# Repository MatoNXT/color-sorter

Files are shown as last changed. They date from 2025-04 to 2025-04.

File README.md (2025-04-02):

# Třídička barev pomocí Lego Mindstorms

**Autor:** Martin Mušec, třída A4b, SPSE Jecna

## 🛠️ Použitý hardware
- **EV3 Brick:** Centrální řídicí jednotka, která zpracovává informace ze senzorů a ovládá celý třídicí systém.
- **Lego Color Sensor:** Senzor, který automaticky rozpoznává barvy tříděných předmětů a umožňuje jejich rychlé roztřídění.
- **Lego Motor:** Zajišťuje pohyb pásu a přesouvání předmětů do správných pozic dle určené barvy.
- **Lego Touch Sensor:** Dotykový senzor umožňující snadné manuální spuštění a zastavení procesu třídění.
- **NXT Servo (Mindstorms) + Micro Servo SG90:** Originální servomotor řady Mindstorms NXT a malý přesný servomotor SG90, umožňující jemné a přesné třídění předmětů podle jejich barvy.

## 💻 Použitý software
- **Ev3dev + MicroPython + Pybricks:** Alternativní operační systém a programovací platforma pro LEGO EV3, umožňující snadné a efektivní programování v jazyce MicroPython.
- **VSCode + Lego Mindstorms plugin:** Vývojové prostředí pro psaní, ladění a správu kódu v Pythonu.
- **OpenSCAD:** Software pro parametrické 3D modelování speciálních součástek projektu.
- **Prusa Slicer:** Program pro přípravu modelů na 3D tisk, umožňující rychlou a přesnou výrobu dílů.
- **GitHub:** Platforma pro správu projektu, verzování a sdílení zdrojového kódu.

## 🖨️ 3D tisk a konstrukce
- **Tiskárna Prusa Mini:** Stolní 3D tiskárna vhodná pro rychlé prototypování a přesnou výrobu plastových dílů.
- **PLA filament:** Ekologicky šetrný materiál s dobrou pevností.
- **MachineBlocks:** Konstrukční prvky kompatibilní s Legem.

## 🌟 Unikátnost mého řešení
- **Programování v Pythonu:** Projekt využívá pokročilý programovací jazyk Python, což umožňuje snadnější, flexibilnější a efektivnější vývoj než použití oficiálního softwaru Lego.
- **Využití open-source technologií:** Používání Ev3dev a Pybricks poskytuje otevřenost a flexibilitu, která umožňuje snadné přizpůsobení systému podle individuálních požadavků.
- **Zakázkové 3D tištěné komponenty:** Specifické konstrukční prvky, vyrobené pomocí 3D tisku, umožňují dokonalé přizpůsobení zařízení, což zvyšuje přesnost a efektivitu třídění.
- **Snadná údržba a modifikovatelnost:** Díky použití standardizovaných Lego dílů, 3D tisku a otevřeného kódu je projekt snadno servisovatelný, modifikovatelný a rozšiřitelný.
- **Transparentní správa projektu:** GitHub umožňuje snadnou spolupráci, verzování kódu a dokumentaci, což usnadňuje zapojení dalších vývojářů.
- **Ekologický přístup:** Použití biologicky rozložitelného PLA filamentu dělá projekt nejen technologicky inovativní, ale i šetrný k životnímu prostředí.

## 📩 Kontaktní informace
📧 martin@musec.cz | 💼 LinkedIn: [Martin Musec](https://www.linkedin.com/in/martin-musec/) | 💻 GitHub: [MatoNXT/color-sorter](https://github.com/MatoNXT/color-sorter)

## 📝 Summary (EN)

This project presents an automatic color sorter developed using Lego Mindstorms EV3 technology. It leverages advanced sensors and precision motors to automatically detect, sort, and place objects according to their color. Programmed in Python, utilizing the open-source Ev3dev and Pybricks frameworks, this project demonstrates flexibility, efficiency, and customizability beyond traditional Lego software solutions. Furthermore, the integration of custom-designed, 3D-printed parts made with eco-friendly PLA filament enhances the functionality and adaptability of the sorter. This innovative approach allows easy modification and scalability, suitable for various educational and practical applications.

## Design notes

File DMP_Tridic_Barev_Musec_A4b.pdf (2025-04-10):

# Střední Průmyslová Škola Elektrotechnická Ječná

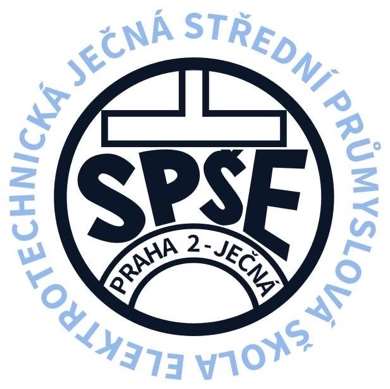
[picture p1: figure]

## DLOUHODOBÁ MATURITNÍ PRÁCE

## Třídič předmětů podle barev s využitím platformy Lego Mindstorms

## 2025 Martin Mušec

# Střední Průmyslová Škola Elektrotechnická Ječná

## DLOUHODOBÁ MATURITNÍ PRÁCE

## Třídič předmětů podle barev s využitím platformy Lego Mindstorms

## Sorter of objects by color using the Lego Mindstorms platform

## Autor: Martin Mušec, A4b Škola: SPŠE Ječná, Ječná 30, 120 00 Praha 2 Vedoucí práce: Ing. Martin Peter

# Prohlášení

Prohlašuji, že jsem svou práci DMP vypracoval samostatně a použil jsem pouze zdroje a literaturu uvedené v seznamu bibliografických záznamů.
Dále prohlašuji, že tištěná a elektronická verze této práce jsou totožné.
Nemám žádný závažný důvod bránící zpřístupnění této práce v souladu se zákonem č. 121/2000 Sb., o právu autorském, právech souvisejících s právem autorským a o změně některých zákonů (autorský zákon), ve znění pozdějších předpisů.
V Praze dne 10.4.2025 | _______________________________
| Martin Mušec

# Poděkování

Rád bych poděkoval vedoucímu práce Ing. Martinu Peterovi za vedení, odbornou podporu a cenné připomínky během celé realizace projektu. Jeho zkušenosti a směřování mi pomohly lépe uchopit technické i dokumentační aspekty této práce.

Mé poděkování patří také panu učiteli Zdeňku Vondrovi za inspirativní výuku, technické rady a trpělivé vedení při praktických cvičeních z automatizace a robotiky, která významně ovlivnila podobu výsledného řešení.

Zvláštní dík si zaslouží můj tatínek, který mi poskytl své staré zásoby LEGO Mindstorms, zapůjčil 3D tiskárnu, zasvětil mě do tajů 3D tisku a pomohl mi vybrat a pochopit správná softwarová řešení. Jeho pomoc byla pro realizaci projektu neocenitelná.

Dále děkuji také firmě SIDAT za zkušenosti získané během odborné praxe, které přispěly k návrhu konstrukce a pochopení principů reálné automatizace.

Velké díky patří i mé rodině a spolužákům za jejich podporu, trpělivost a motivaci během vývoje projektu.

# Anotace

Tento projekt představuje simulaci automatizované třídičky předmětů podle barvy, postavenou na vzdělávací platformě LEGO Mindstorms EV3. Pomocí barevného senzoru, motorů a servomotorů zařízení napodobuje funkci skutečného automatizačního systému, který rozeznává a třídí objekty na základě jejich barvy. Řídicí software je vyvinut v jazyce MicroPython s využitím open-source systému ev3dev a platformy Pybricks, což zajišťuje flexibilitu, snadnou úpravu a možnost dalšího rozvoje. Součástí zařízení jsou také uživatelsky upravené díly konstrukce, navržené na míru potřebám projektu a vytištěné na 3D tiskárně z ekologického materiálu PLA (Polyactic acid).

# Klíčové slova

EV3; třídění podle barvy; MicroPython; ev3dev; pybricks, SG90 servo; NXTServo; OpenSCAD; MachineBlocks; PLA filament; Prusa Mini; Open-source

# Annotation

This project presents a simulation of an automated color-sorting system, built on the educational platform LEGO Mindstorms EV3. Using a color sensor, motors, and servos, the device mimics the functionality of a real industrial automation system that identifies and sorts objects based on their color. The control software is developed in MicroPython using the open-source ev3dev system and the Pybricks platform, providing flexibility, easy customization, and potential for future development. The device also includes custom-designed structural components, tailored to the specific needs of the project and 3D printed using eco-friendly PLA material (Polyactic acid).

# Key words

EV3; color sorting; MicroPython; ev3dev; pybricks, SG90 servo; NXTServo; OpenSCAD; MachineBlocks; PLA filament; Prusa Mini; Open-source

# Zadání

Navrhněte třídič barev za pomocí Lego Mindstorms.
1. Použijte dotykový senzor, aby se program spustil a barevný senzor který bude snímat barvy předmětů.
2. Použijte motory k pohybu pásu, na kterém předměty budou a k třídění daných předmětu podle barev.

# Obsah

Střední Průmyslová Škola Elektrotechnická Ječná | Martin Mušec, A4b
Třídič předmětů podle barev s využítím platformy Lego Mindstorms | 8

# 1. Úvod

## 1.1. Jak funguje barevný senzor?

### 1.1.1. Co je to barva?

Za barvy, jak je známe, jsou zodpovědné dvě věci – světlo a naše oči. Zjednodušeně řečeno, rozdíl mezi jednotlivými barvami je v množství energie, které příslušný paprsek světla má. V tabulce níže jsou uvedeny různé druhy světla.

Obrázek 1: Zobrazení různých typů elektromagnetického záření
Takzvané gama paprsky „mají“ největší množství energie, zatímco rádiové vlny nejmenší. Uprostřed, kde jsou viditelné barevné pruhy, se nachází světlo, které můžeme vidět – tzv. viditelné světlo. Z viditelného spektra má fialové světlo nejvíce energie a červené nejméně.
Různé objekty vidíme v různých barvách v závislosti na tom, jaké světlo pohlcují a jaké odrážejí. Například objekty, které nazýváme černé, pohlcují veškeré světlo, a tedy i hodně energie. Naopak bílé objekty odrážejí veškeré světlo a pohlcují ho mnohem méně. Proto nám bývá v létě větší horko v černém oblečení než v bílém.

### 1.1.2. Jak vidíme barvy?

V našich očích máme tři typy čípků. Každý typ je citlivý buď na červené, zelené nebo modré světlo. Každý čípek posílá do mozku signál o intenzitě světla, které zaznamenal. Díky informacím o množství červené, zelené a modré v každém světelném paprsku je náš mozek schopen „vidět“ různé barvy.
A jak vidí barvy roboti?
Místo očí mají roboti senzory. Podobně jako lidé, i roboti používají tři typy senzorů. Každý typ detekuje intenzitu červeného, zeleného nebo modrého světla. Kombinací informací ze tří senzorů dokáže robot určit, jakou barvu „vidí“.

## 1.2. Různé typy snímačů barev

### 1.2.1. RGB senzory (Red, Green, Blue)

Je to nejzákladnější typ barevného senzoru. Funguje na principu měření intenzity světla v červené, zelené a modré spektrální složce. Na výstupu se pak objevují kombinace hodnot RGB, ze kterých se pak určuje výsledná barva. Nejběžněji se používají v průmyslových třídících systémech a displejích. Použivají se v

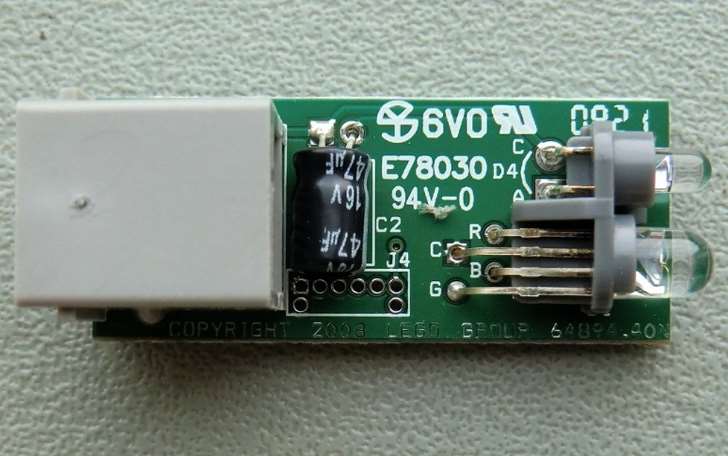
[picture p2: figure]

Třídič předmětů podle barev s využítím platformy Lego Mindstorms | 9

automatickém nastavení jasu v displejích, třídění objektu podle barvy a rozpoznávání barev v robotice (např. cledování barevné čáry).

### 1.2.2. Spektrální sensory

Funguje na stejným principu jako RGB senzory, ale měří světlo v širším spektru barev nejenom RGB. Díky tomu, že umí analyzovat ve vice úzkých vlnových délek světla, může poskytnout přesnější výsledky. Tenhle sensor se používá v laboratořích, medicíně a přesných měřících aplikacích. Používají se v diagnostice materiálů, kontrole kvality potravin a analýze světelných zdrojů.

### 1.2.3. Infračervené sensory s barevnou detekcí

Dokážou detekovat světlo mimo viditelné spektrum, zejména infračervené a blízké infračervené záření. Používají se v nočním vidění, bezpečnostních systémech a medicíně.
Použití: noční vidění (např. v bezpečnostních kamerách).
Optické snímače pro třídění materiál. Lékařská termografie

### 1.2.4. LEGO EV3 barevný senzor

Je to digitální senzor, který dokáže detekovat barvu nebo intenzitu světla, které vstupuje malým vstupem na přední straně senzoru. Tento senzor lze používat ve třech různých režimech: režim rozpoznávání barev, režim intenzity odraženého světla a režim intenzity okolního světla.
V režimu rozpoznávání barev dokáže senzor rozlišit sedm barev — černou, modrou, zelenou, žlutou, červenou, bílou a hnědou — plus „žádná barva“ (No Color). Díky této schopnosti rozlišovat barvy může být sensor použít ke stave třídičky.
Vzorkovací frekvence barevného senzoru je 1 kHz (1000 měření za sekundu).
Pro co nejpřesnější výsledky je v režimech rozpoznávání barev a odraženého světla potřeba držet senzor v pravém úhlu a těsně u povrchu, který zkoumá – ale nesmí se ho dotýkat.

Obrázek 2: Jak vypadá Color Sensor uvnitř

Třídič předmětů podle barev s využítím platformy Lego Mindstorms | 10

# 2. Funkce systému

Systém třídění barev funguje jako automatizovaný proces, který využívá senzory k detekci barvy objektů a následně je pomocí motorů třídí do příslušných přihrádek. Níže je popsán celý proces krok za krokem:

### 1. Spuštění systému

Systém je ovládán dotykovým senzorem (Touch Sensor).
Uživatel spustí proces třídění stiskem tlačítka – tím se aktivuje hlavní smyčka programu. Tímto způsobem lze systém jednoduše zapnout nebo zastavit bez nutnosti připojení k počítači.

### 2. Aktivace dopravníku

Po spuštění se zapne motor připojený k pásovému dopravníku (motor na portu A).
Dopravník začne pohybovat objekty (např. kuličky nebo kostky) směrem k barevnému senzoru.

### 3. Detekce barvy

Jakmile se předmět dostane pod barevný senzor (Color Sensor na portu S2), senzor načte jeho barvu. Senzor pracuje v režimu rozpoznávání barev (Color Mode), ve kterém je schopen detekovat:
- černou, modrou, zelenou, žlutou, červenou, bílou, hnědou
- nebo „žádnou barvu“ (pokud nic není detekováno)

Data ze senzoru jsou okamžitě zpracována řídicí jednotkou EV3.

### 4. Vyhodnocení barvy a rozhodnutí o směru

EV3 vyhodnotí detekovanou barvu a rozhodne, do které přihrádky má být předmět zařazen. Každé barvě je přiřazena konkrétní pozice ramene, kterou nastavuje příslušné mikro servo (SG90). Rameno slouží jako přepínač směru – nasměruje předmět do správné výstupní trasy.

### 5. Nastavení serva a třídění

Pomocí rozhraní I2C vyšle EV3 příkaz do zařízení NXTServo, které ovládá tři serva SG90. Konkrétní servo se otočí do předem definované pozice odpovídající rozpoznané barvě. Když se objekt dostane na konec dopravníku, je veden do správné výstupní přihrádky.

### 6. Plynulý průběh a opakování

Systém pokračuje v třídění dalších předmětů, dokud není proces přerušen (např. opětovným stiskem dotykového senzoru). Třídění probíhá automaticky a plynule díky kombinaci dopravníku, senzoru a přesného řízení serv

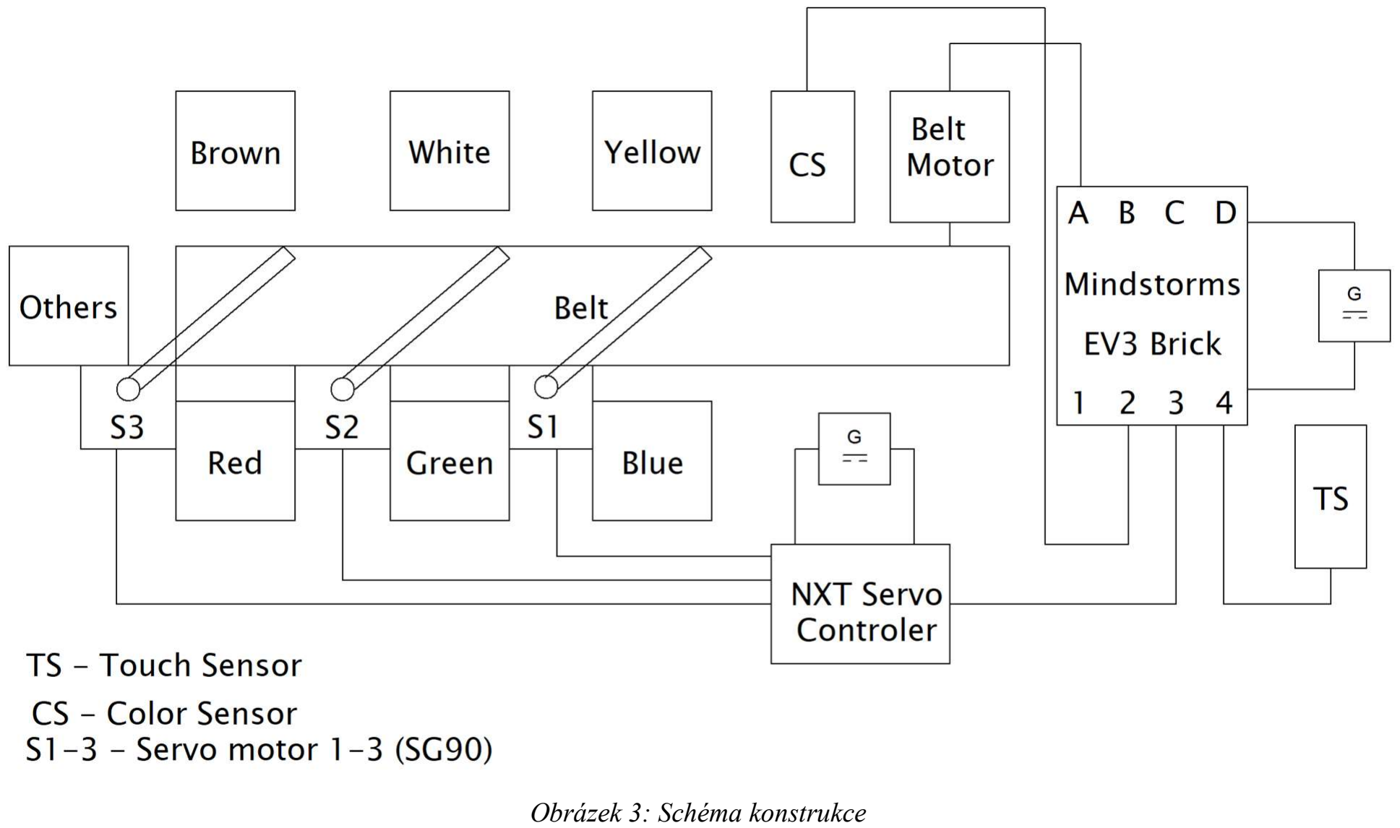
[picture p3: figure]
Obrázek 3: Schéma konstrukce

Třídič předmětů podle barev s využítím platformy Lego Mindstorms | 11

# 3. Řešení a konstrukce

Projekt je postaven na kombinaci otevřeného softwarového prostředí a modulární mechanické konstrukce. Cílem bylo vytvořit systém, který je nejen funkční, ale také snadno rozšiřitelný, modifikovatelný a udržitelný. Celý návrh integruje programování, elektroniku, 3D modelování a robotiku.
Níže uvedený obrázek schematicky znázorňuje zapojení jednotlivých komponentů systému. Zobrazuje propojení mezi EV3, senzory, servomotory a napájecími zdroji. Schéma slouží jako vizuální podpora k popisu funkce systému.

Popis schématu:
- EV3 (řídicí jednotka) je napájena pomocí 5 V USB zdroje s step-up měničem na 9V.
- Color Sensor (S2) snímá barvu objektů na pásu.
- Touch Sensor (S4) slouží k manuálnímu spuštění/zastavení třídění.
- Motor (A) pohání pásový dopravník.
- NXTServo (S3) je připojen k EV3 přes I2C a ovládá tři SG90 serva.
- Serva jsou napájena z LEGO bateriového boxu upraveného na 6 V.
- Veškeré napájení a komunikace jsou oddělené pro zajištění stability a bezpečnosti provozu.

Třídič předmětů podle barev s využítím platformy Lego Mindstorms | 12

## 3.1. Softwarové řešení

Hlavní logika třídicího algoritmu je napsána v MicroPythonu a běží přímo na zařízení EV3. Pomocí knihovny Pybricks je zajištěna komunikace s barevným senzorem, motory, dotykovým senzorem a přes rozhraní I2C také s externím řadičem servomotorů (NXTServo). Program je strukturován do funkcí, což usnadňuje jeho ladění, úpravy a případné rozšíření o nové funkce nebo schopnost třídit jiné barvy. Jedním z klíčových problémů při vývoji softwéru třídicky, bylo získání stabilního a spolehlivého barevného čtení. Během pohybu předmětu po pásu může totiž barevný senzor zachytit přechodové nebo falešné hodnoty způsobené vibracemi, nedokonalým osvětlením nebo odlesky.
Barevný senzor (Color Sensor) snímá barvu s vysokou frekvencí až 1000 měření za sekundu, což umožňuje rychlé reakce, ale zároveň zvyšuje pravděpodobnost kolísání naměřených hodnot.
Pro řešení tohoto problému byl implementován následující postup:
- Vytváří se buffer, do kterého se ukládá několik po sobě jdoucích měření barvy.
- Funkce get_sensor_color() analyzuje tento buffer a zjišťuje, zda se některá barva vyskytuje opakovaně v dostatečné míře. Pokud podíl nejčastější barvy překročí nastavený práh stability, je tato barva vyhodnocena jako platná.
- Tento přístup výrazně zvyšuje odolnost vůči šumu a náhodnému přečtení okolních ploch nebo samotného pásu, a přispívá tak k přesnosti celého třídicího procesu.
Zdrojový kód je k dispozici na téhle adrese:
- https://github.com/MatoNXT/color-sorter/blob/main/MMSorter/main.py

## 3.2. Použitý software

### 3.2.1. ev3dev + MicroPython + Pybricks[3][5]

Projekt využívá alternativní open-source operační systém ev3dev, který běží na řídicí jednotce LEGO EV3. V kombinaci s knihovnou Pybricks umožňuje programování v jazyce MicroPython, což výrazně zvyšuje flexibilitu a efektivitu vývoje oproti původnímu LEGO softwaru. Programátor má plnou kontrolu nad senzory, motory i časováním.

### 3.2.2. Visual Studio Code + LEGO Mindstorms Extension[7]

Pro psaní a správu kódu bylo využito moderní vývojové prostředí VSCode spolu s rozšířením pro LEGO Mindstorms. Toto prostředí usnadňuje práci s projektem díky funkcím jako zvýraznění syntaxe, připojení k zařízení, integrovaný terminál a ladění.

### 3.2.3. OpenSCAD [6]

Veškeré uživatelsky upravené 3D modely byly navrženy v nástroji OpenSCAD, který umožňuje parametrické modelování. Díky tomu lze konstrukční díly snadno přizpůsobit požadavkům projektu, měnit rozměry nebo tvar úpravou několika parametrů.

Třídič předmětů podle barev s využítím platformy Lego Mindstorms | 13

### 3.2.4. PrusaSlicer[9]

Pro přípravu modelů k tisku byl využit software PrusaSlicer, který umožňuje precizní nastavení parametrů tisku, optimalizaci podpor a náhledy výsledné struktury. Výsledkem je kvalitní a efektivní výroba 3D dílů z PLA.

### 3.2.5. GitHub [8]

Celý projekt je spravován pomocí platformy GitHub, která umožňuje verzování kódu, dokumentaci, sledování změn a spolupráci více vývojářů. Díky tomu je projekt transparentní, otevřený pro další rozvoj a snadno se dá sdílet.

### 3.2.6. Mechanické řešení[9]

Zařízení kombinuje standardní LEGO konstrukční prvky s uživatelsky navrženými 3D tištěnými díly, které zajišťují:
- uchycení mikroserv, (Obrázek 13)
- přesné vedení předmětů po dopravníku, (Obrázek 11)
- montážní prvky pro barevný senzor, (Obrázek 12)
- uchyceni upravených lego dílu na mikroserva (Obrázek 13)
Tyto díly byly navrženy tak, aby rozšířily možnosti klasických LEGO prvků a zlepšily funkčnost systému.
3.2.7. 3D tisk a vlastní konstrukční díly
V rámci projektu byly navrženy a vyrobeny vlastní konstrukční prvky, které rozšiřují možnosti standardních LEGO dílů a umožňují přesné uchycení komponent, vedení objektů či integraci ne-Legových prvků, jako jsou SG90 serva. K jejich výrobě byla využita technologie 3D tisku.
Použitá technologie 3D tisku [9]
- 3D tiskárna Prusa Mini – spolehlivá stolní tiskárna pro FDM (Fused Deposition Modeling) fungují na principu tavení plastového filamentu, vrstva po vrstvě, ideální pro rychlou a přesnou výrobu funkčních plastových dílů.
- Materiál: PLA filament – biologicky rozložitelný plast s dobrou pevností, vhodný pro technické a konstrukční aplikace. Je ekologický a snadno tisknutelný, což urychluje prototypování.
MachineBlocks[2] a jejich úprava v OpenSCADu
- MachineBlocks je knihovna modulárních stavebních bloků kompatibilních s LEGO systémem, určená pro 3D tisk.
- Pro tento projekt byly některé bloky upraveny pomocí parametrického modelování v OpenSCADu, aby přesně vyhovovaly specifickým požadavkům:
- Změna rozměrů pro přesné usazení SG90 servomotorů
- Přidání otvorů nebo výřezů pro kabely, I2C konektory a šroubky

Třídič předmětů podle barev s využítím platformy Lego Mindstorms | 14
- Přizpůsobení výšky a tloušťky podle rozměrů okolních LEGO prvků
Výhodou použití OpenSCADu je možnost snadné replikace a úpravy díky parametrům – úprava jednoho čísla automaticky změní celý model.

## 3.3. Napájení systému a řízení napěťových úrovní

Funkčnost celého zařízení závisí nejen na správném programování a konstrukci, ale také na zajištění stabilního a vhodného napájení jednotlivých komponent. V projektu bylo potřeba řešit rozdílné napěťové požadavky mezi jednotkou EV3, servy a dalšími prvky.

### 3.3.1. Napájení jednotky EV3

Řídicí jednotka LEGO EV3 běžně pracuje s napětím 9 V, a může být napájena buď pomocí originálního LEGO akumulátoru, nebo šesti AA bateriemi. Pro zajištění delší výdrže a stabilního napětí bylo zařízení připojeno na externí USB zdroj (5 V) prostřednictvím step-up měniče, který napětí zvedá na požadovaných 9 V. Toto řešení je efektivní, bezpečné a zároveň cenově dostupné.

### 3.3.2. Napájení servomotorů (SG90)

Řídicí jednotka NXTServo byla napájena prostřednictvím upraveného kabelu připojeného k LEGO bateriovému boxu, Mikroserva typu SG90 vyžadují napájení kolem 5–6 V pro spolehlivý provoz. K jejich napájení byl použit upravený LEGO bateriový box (Obrázek 16), do kterého byly vloženy klasické AAA baterie. Box byl následně upraven tak, aby poskytoval stabilní výstupní napětí 6 V (Obrázek 17), vhodné pro napájení SG90 serv. Tímto způsobem bylo možné zachovat kompatibilitu s LEGO systémem a zároveň zajistit požadovanou úroveň napájení pro serva.

### 3.3.3. Úprava napájecích konektorů

Pro propojení LEGO komponent s běžnou elektronikou (např. SG90 serva, řídicí jednotka NXTServo) bylo nezbytné upravit napájecí a signálové konektory (Obrázek 18), protože LEGO využívá proprietární konektorový systém, který není přímo kompatibilní se standardními I2C zařízeními ani běžnými servy. Byla provedena následující praktická řešení:
- Vlastní redukce byly vytvořeny z rozstřižených LEGO kabelů. Jejich konce byly upraveny tak, aby umožňovaly napojení na běžné piny (použitý dutinkový konektory), čímž vznikl přechodový kabel mezi LEGO systémem a běžnou elektronikou.
- Řídicí jednotka NXTServo byla napájena prostřednictvím upraveného kabelu připojeného k LEGO bateriovému boxu, který byl upraven tak, aby poskytoval stabilní výstup 6 V potřebný pro provoz SG90 servomotorů.
- Kabely byly vedeny tak, aby bylo zachováno správné napěťové rozložení a polarita. Pro bezpečnost a stabilitu spojení byly konektory mechanicky zajištěny (smršťovací bužírkou nebo tavným lepidlem)

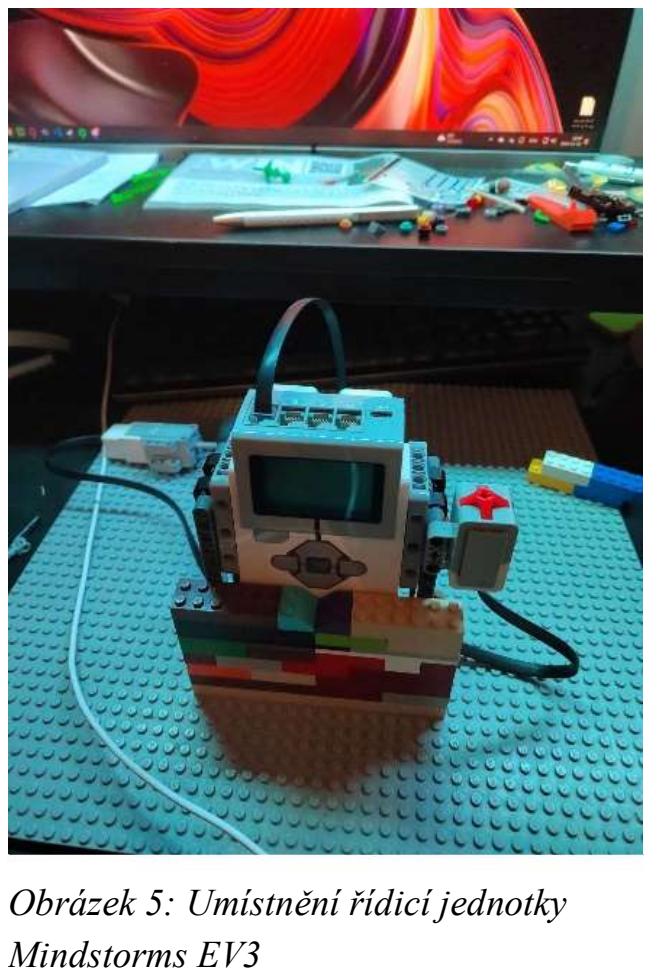
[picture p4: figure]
Mindstorms EV3
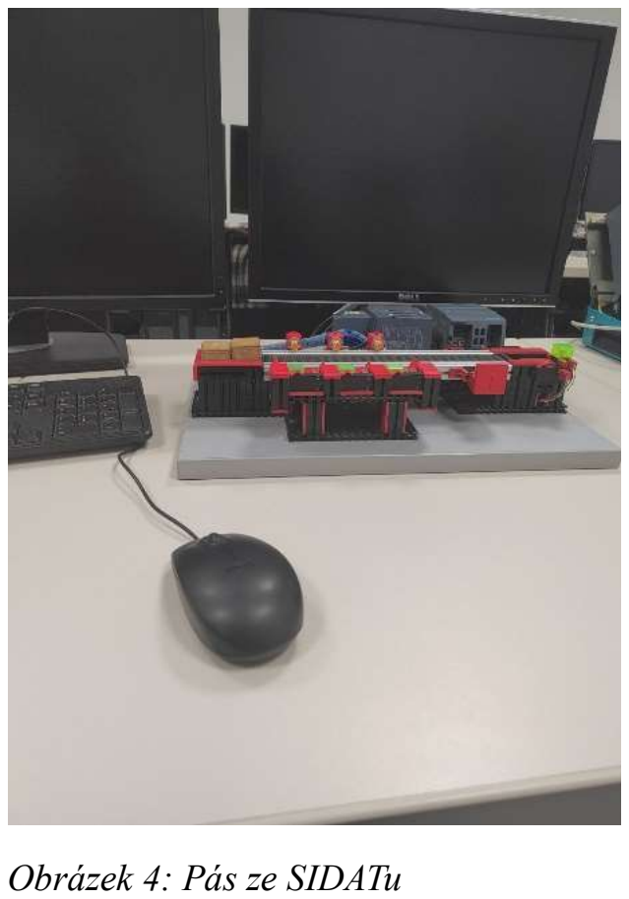
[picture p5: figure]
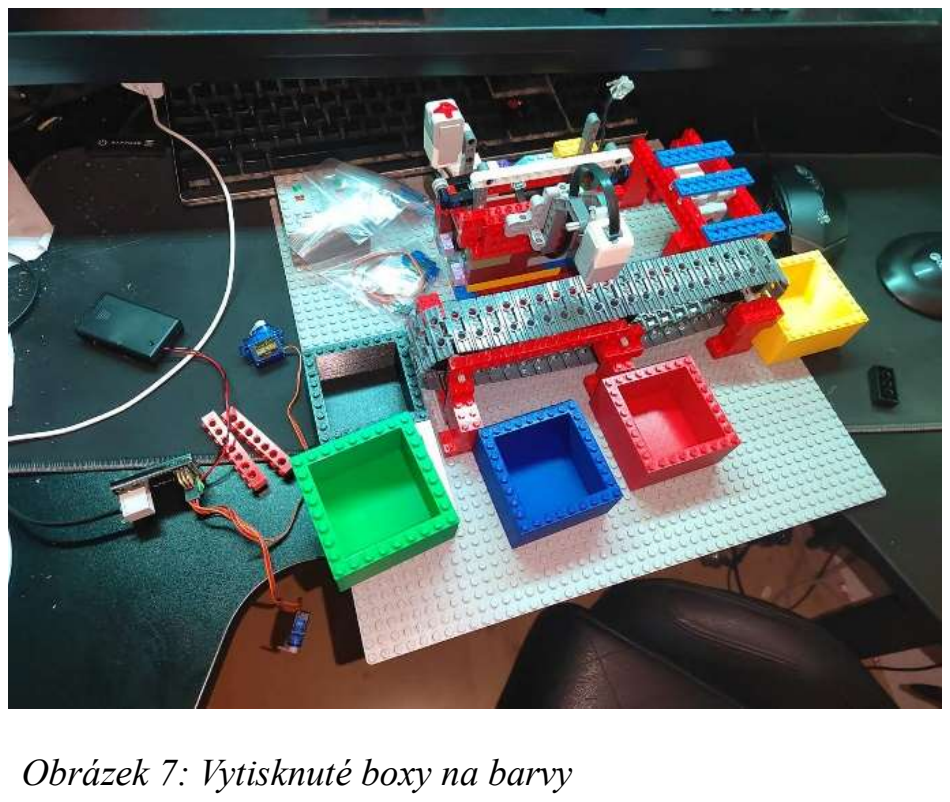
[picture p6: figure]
Obrázek 7: Vytisknuté boxy na barvy
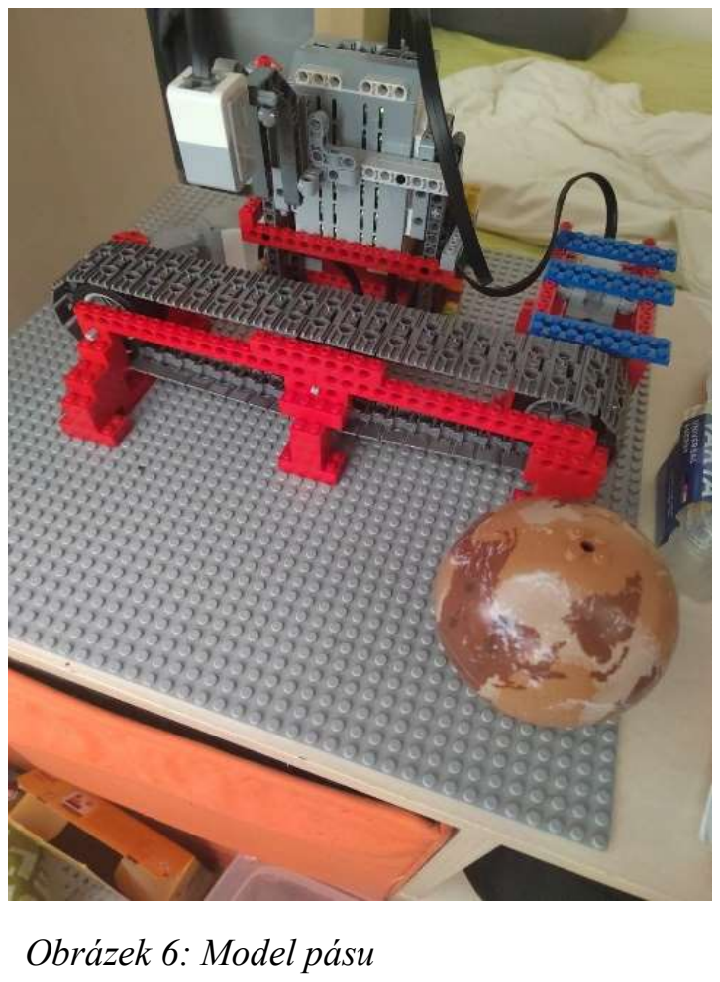
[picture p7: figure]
Obrázek 6: Model pásu

Třídič předmětů podle barev s využítím platformy Lego Mindstorms | 15
Obrázek 4: Pás ze SIDATu | Obrázek 5: Umístnění řídicí jednotky

## 3.4. Stavba

Návrh a sestavení konstrukce pásového dopravníku zabralo značné množství času a experimentování. Klíčovým úkolem bylo správně zvolit ozubená kolečka, určit vhodné rozmístění hnacích a napínacích částí a navrhnout umístění misek pro roztříděné barvy.
Nejprve jsem si vytvořil několik jednoduchých modelů a náčrtků, jak by mohla výsledná konstrukce vypadat. Inspiraci jsem čerpal ze skutečných pásových dopravníků, se kterými jsem měl možnost pracovat během odborné praxe ve firmě SIDAT, a také z výuky předmětu Cvičení z automatizace a robotiky, vedeného panem učitelem Zdeňkem Vondrou. Tyto zkušenosti mi pomohly lépe pochopit principy mechanického návrhu a přenést je do prostředí LEGO konstrukce.

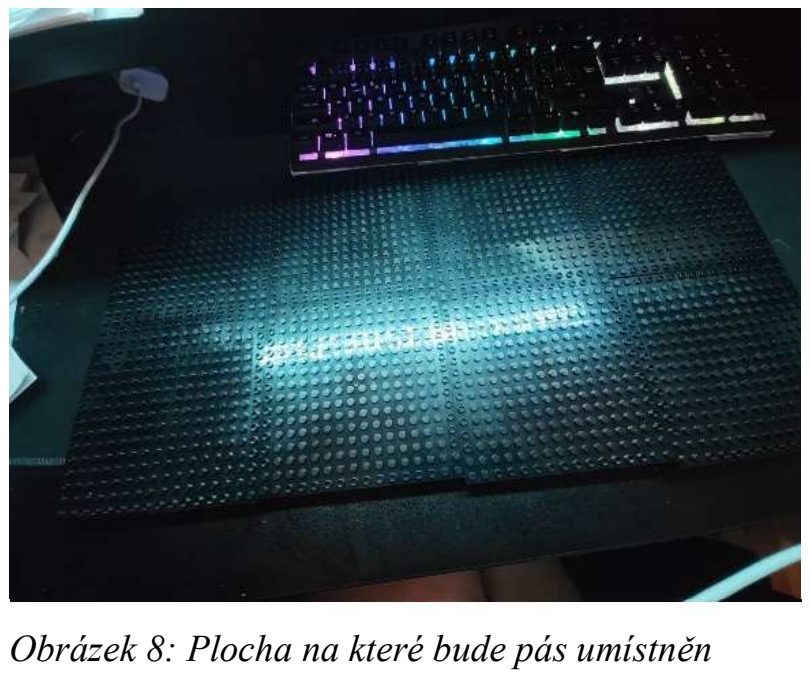
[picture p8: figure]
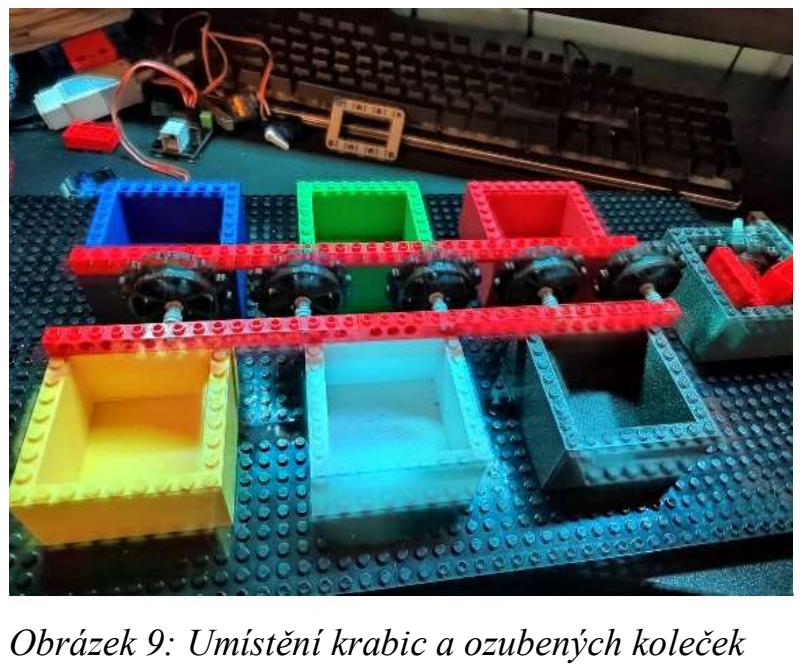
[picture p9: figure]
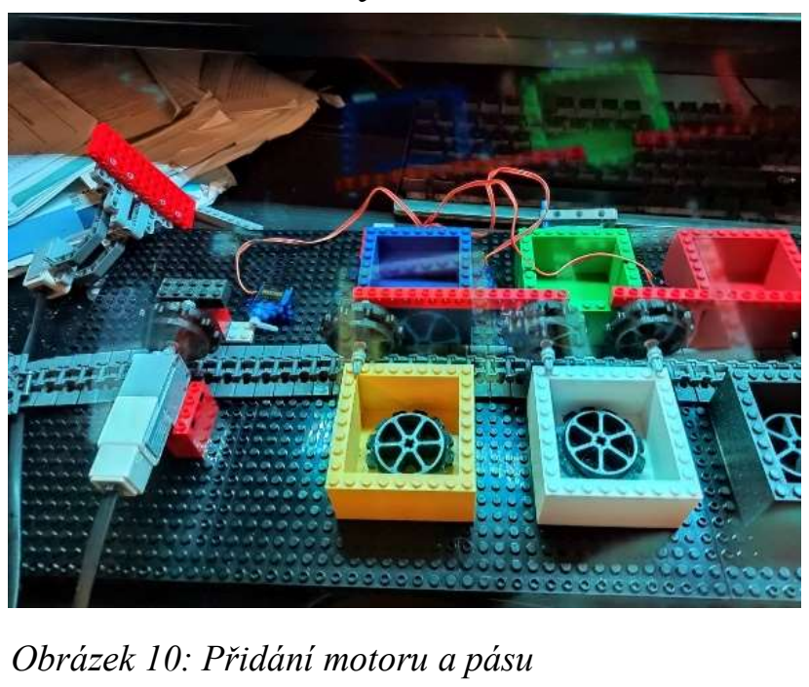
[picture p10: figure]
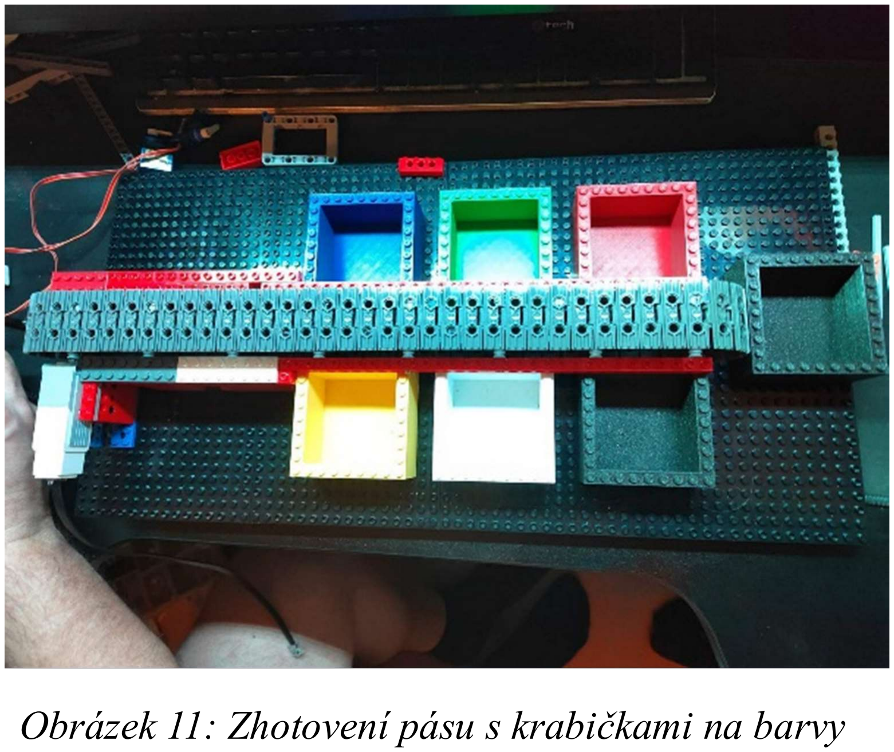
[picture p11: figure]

Třídič předmětů podle barev s využítím platformy Lego Mindstorms | 16

### 3.4.1. Vývoj prototypu a ladění mechaniky

Během vývoje zařízení vzniklo několik verzí konstrukce, které sloužily k testování a postupnému vylepšování mechanických částí i celkového chování systému. Každá nová verze byla výsledkem praktických testů, zpětné vazby a dolaďování detailů. Nedílnou součástí každé fáze bylo také průběžné ladění 3D tištěných dílů, které byly upravovány podle potřeb a chování jednotlivých částí v reálném provozu (Obrázek 20).
- První verze sloužila jako základní prototyp. Testoval se základní princip pohybu pásu, uchycení misek a typ použitého ozubení. Současně byly vytvořeny první 3D díly (např. držák senzoru), které se následně ukázaly jako nevhodné z hlediska stability a rozměrů.
- Druhá verze přinesla zpevnění konstrukce a přesnější vedení pásu. V této fázi byly 3D modely přepracovány pro pevnější uchycení k LEGO konstrukci a upravovaly se rozměry dle reálných tolerancí výtisků.
- Třetí verze se soustředila na časovou synchronizaci jednotlivých činností, tedy pohybu pásu, snímání barvy a aktivace serv pro třídění. Došlo zde i k dalším úpravám 3D dílů – zejména držáků SG90 serv, které musely přesně pasovat a zároveň umožnit volný pohyb ramena.
- Finální verze představuje optimalizované zařízení s vyladěnými mechanickými detaily, stabilní konstrukcí a přesně seřízenými vlastními 3D tištěnými komponenty, které hrají klíčovou roli ve funkčnosti celého systému.
Obrázek 8: Plocha na které bude pás umístněn | Obrázek 9: Umístění krabic a ozubených koleček
Obrázek 10: Přidání motoru a pásu | Obrázek 11: Zhotovení pásu s krabičkami na barvy

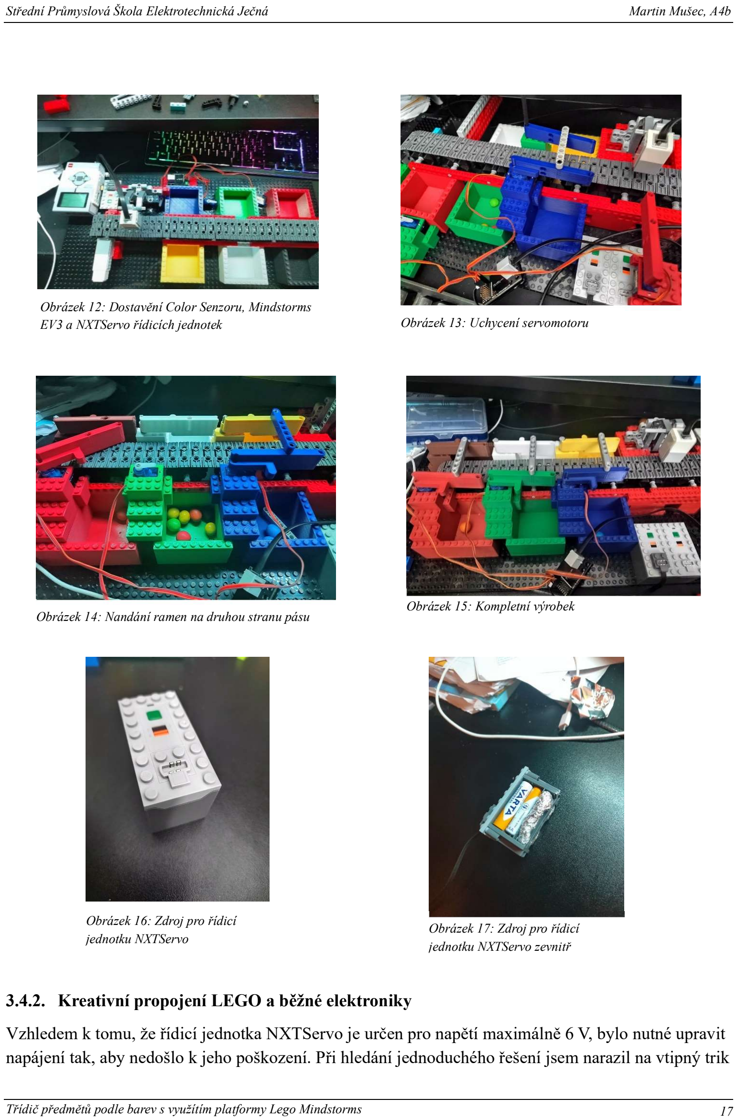
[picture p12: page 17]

Třídič předmětů podle barev s využítím platformy Lego Mindstorms | 17

### 3.4.2. Kreativní propojení LEGO a běžné elektroniky

Vzhledem k tomu, že řídicí jednotka NXTServo je určen pro napětí maximálně 6 V, bylo nutné upravit napájení tak, aby nedošlo k jeho poškození. Při hledání jednoduchého řešení jsem narazil na vtipný trik

Obrázek 12: Dostavění Color Senzoru, Mindstorms
EV3 a NXTServo řídicích jednotek | Obrázek 13: Uchycení servomotoru
Obrázek 14: Nandání ramen na druhou stranu pásu | Obrázek 15: Kompletní výrobek

Obrázek 16: Zdroj pro řídicí
jednotku NXTServo | Obrázek 17: Zdroj pro řídicí
| jednotku NXTServo zevnitř

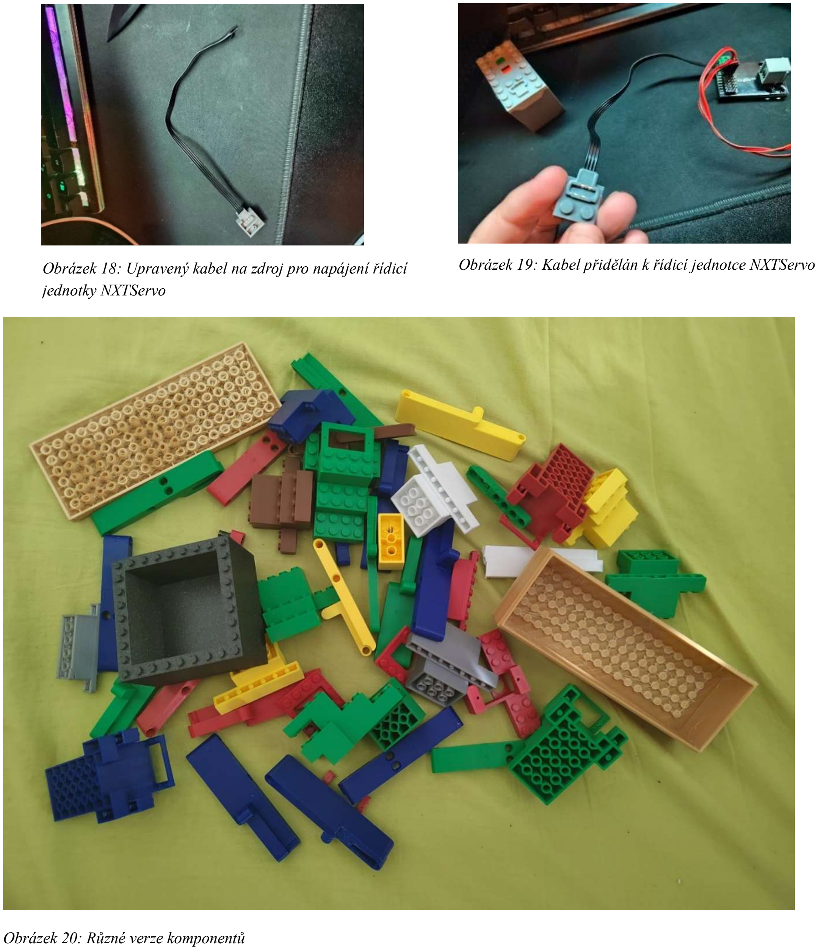
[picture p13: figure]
jednotky NXTServo; Obrázek 20: Různé verze komponentů

Třídič předmětů podle barev s využítím platformy Lego Mindstorms | 18

na internetu – nahradit dvě baterie v LEGO bateriovém boxu kousky alobalu (Obrázek 17), čímž se celkové napětí sníží z 9 V na přibližně 6 V. Tento „low-tech“ hack se ukázal jako překvapivě funkční a umožnil bezpečné napájení servomotorů bez nutnosti složité elektroniky.

Aby bylo možné napájet řídicí jednotku NXTServo, bylo nutné upravit jeden LEGO kabel, který tak byl obětován pro adaptér připojení ke zdroji napájení.

Obrázek 18: Upravený kabel na zdroj pro napájení řídicí

Obrázek 19: Kabel přidělán k řídicí jednotce NXTServo

Třídič předmětů podle barev s využítím platformy Lego Mindstorms | 19

# 4. Závěr

Projekt automatizované třídičky barev pomocí LEGO Mindstorms EV3 ukazuje, že i s dostupnými vzdělávacími technologiemi lze vytvořit plnohodnotné zařízení, které napodobuje principy průmyslové automatizace. Kombinací senzoriky, programovatelného řízení, vlastních 3D tištěných dílů a úprav pro kompatibilitu s běžnou elektronikou vznikl technicky funkční systém
Hlavním přínosem projektu je schopnost automatického rozpoznání a mechanického třídění předmětů podle barvy. Díky využití open-source softwaru (ev3dev, Pybricks, OpenSCAD) a běžně dostupného hardwaru (SG90 serva, NXTServo) bylo možné systém výrazně přizpůsobit konkrétním požadavkům a rozšířit jeho možnosti nad rámec standardního LEGO ekosystému.
Projekt nabízí prostor pro další technické rozšíření a vylepšení. Nejvýznamnějším směrem dalšího vývoje je integrace automatického podavače předmětů, který by umožnil plně autonomní třídění bez nutnosti ručního vkládání objektů. Klíčovým aspektem tohoto rozšíření by byla synchronizace podavače s pásem a čtecí oblastí barevného senzoru, aby byl zajištěn plynulý a přesný průběh třídicího cyklu.
V projektu byly využity moderní přístupy jak po stránce softwaru (programování v Pythonu, verzování přes GitHub), tak i hardwaru (parametrický 3D tisk, úprava napájecích větví a konektorů). Výsledkem je stabilní a opakovatelný systém, který je možné dále rozvíjet – např. o více výstupních třídicích pozic, přesnější měření, dálkové ovládání nebo vizualizaci dat.
Projekt nejen rozvíjí technické znalosti z oblasti robotiky, programování a návrhu elektroniky, ale také podporuje kreativitu, schopnost řešit problémy a pracovat s otevřenými technologiemi. Díky použitým nástrojům a přístupům je ideálním základem pro vzdělávání, prototypování i pokročilejší experimenty v oblasti mechatroniky a automatizace.

Třídič předmětů podle barev s využítím platformy Lego Mindstorms | 20

# 5. Zdroje

[1] Mindsensors – NXTServo User Guide (v3). [online] Dostupné z: http://mindsensors.com/pdfs/NXTServo-v3-User-Guide.pdf
[2] MachineBlocks – Examples: Boxes & Enclosures. [online] Dostupné z: https://machineblocks.com/examples/boxes-enclosures#box-6x6
[3] Pybricks – EV3 MicroPython Documentation. [online] Dostupné z: https://pybricks.com/ev3-micropython/ev3devices.html
[4] PhiloHome – Servo power supply options. [online] Dostupné z: https://www.philohome.com/alimservo/alimservo.htm
[5] EV3dev – Official Documentation. [online] Dostupné z: https://www.ev3dev.org
[6] OpenSCAD – The Programmers Solid 3D CAD Modeller. [online] Dostupné z: https://openscad.org
[7] Microsoft – Visual Studio Code. [online] Dostupné z: https://code.visualstudio.com
[8] GitHub – Color Sorter by MatoNXT. [online] Dostupné z: https://github.com/MatoNXT/color-sorter
[9] Prusa Research – Original Prusa MINI+ a PrusaSlicer. [online] Dostupné z: https://www.prusa3d.com/cs/kategorie/original-prusa-mini/
[10] OpenAI – ChatGPT. [online] Dostupné z: https://openai.com/chatgpt/
[11] LEGO – Oficiální web společnosti LEGO. [online] Dostupné z: https://www.lego.com/en-cz
[12] LEGO Education – EV3 Color Sensor Technical Specifications. [online] Dostupné z: https://education.lego.com/en-us/support/mindstorms-ev3/sensor/color
[13] TowerPro – SG90 Micro Servo Datasheet. [online] Dostupné z: https://www.electronicoscaldas.com/datasheet/SG90Servo.pdf
[14] MachineBlocks – MachineBlocks for OpenSCAD. [online] Dostupné z: https://github.com/MachineAgency/machineblocks
[15] GME – DC/DC měnič step-up. [online] Dostupné z: https://www.gme.cz/v/1507897/modul-dc-dc-menic-step-up-2-28v-2a-s-mt3608

LEGO, the LEGO logo, the Minifigure, DUPLO, the DUPLO logo, NINJAGO, the NINJAGO logo, the FRIENDS logo, the HIDDEN SIDE logo, the MINIFIGURES logo, MINDSTORMS and the MINDSTORMS logo are trademarks of the LEGO Group. ©2023 The LEGO Group. All rights reserved

Třídič předmětů podle barev s využítím platformy Lego Mindstorms | 21

# 6. Seznam obrázků

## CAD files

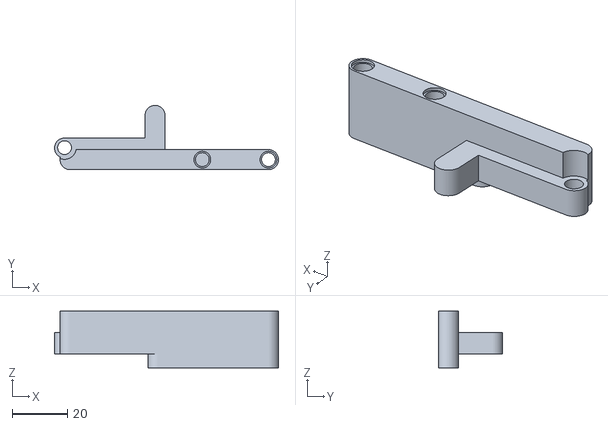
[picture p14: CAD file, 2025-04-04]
stl/arm_horn1.stl
81.3 x 23.3 x 20.6

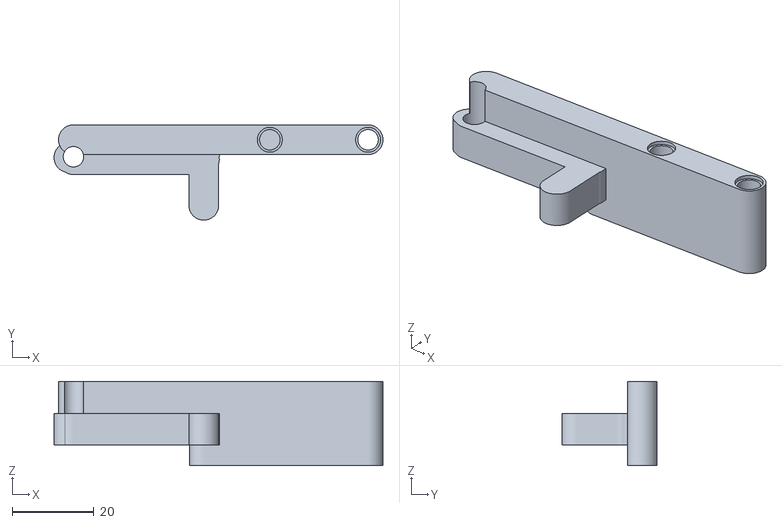
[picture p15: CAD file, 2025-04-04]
stl/servo_horn1.stl
80.4 x 23.3 x 20.6

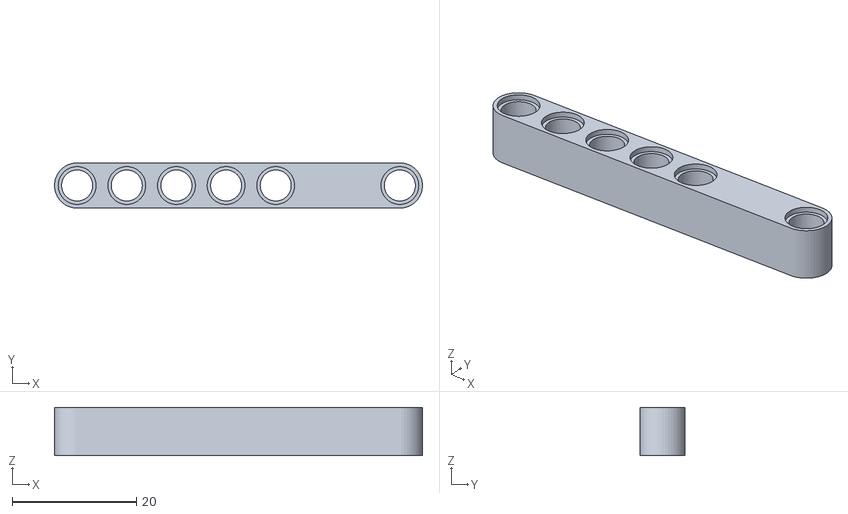
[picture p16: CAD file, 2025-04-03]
stl/arm_horn_bridge1.stl
59.3 x 7.30 x 7.80

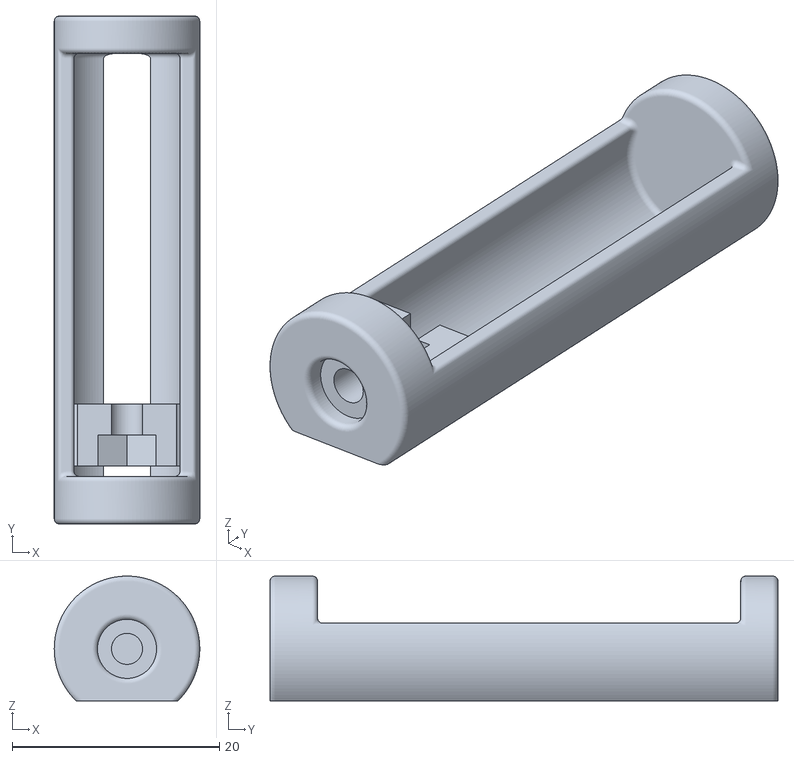
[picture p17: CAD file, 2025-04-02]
stl/Battery_Dummy_Cut_Positiv.stl
14.0 x 49.0 x 12.0

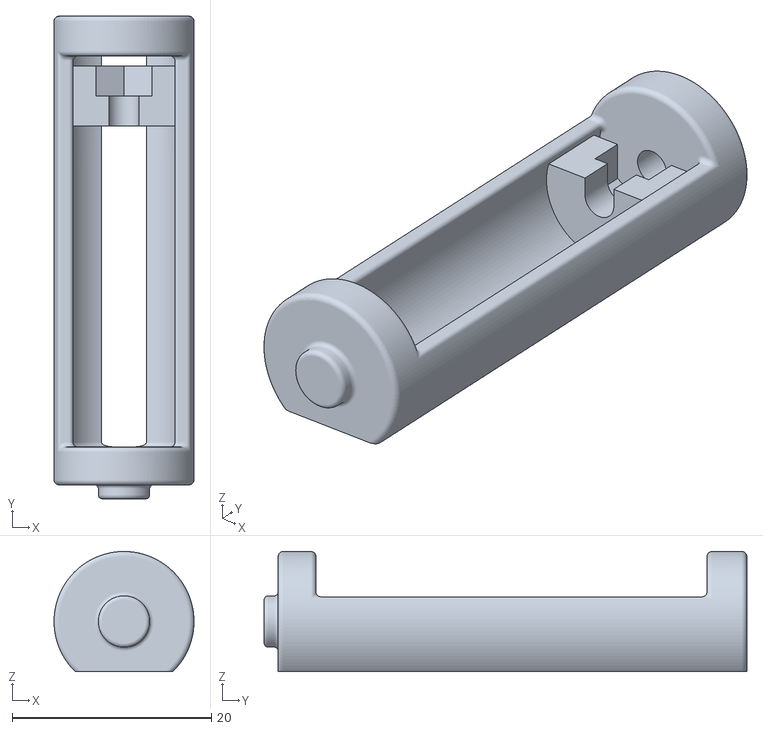
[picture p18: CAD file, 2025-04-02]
stl/Battery_Dummy_Cut_Negativ.stl
14.0 x 48.4 x 12.0

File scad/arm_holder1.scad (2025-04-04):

/**
* MachineBlocks
* https://machineblocks.com/examples/classic-bricks
*
* Copyright (c) 2022 - 2025 Jan Philipp Knoeller <pk@pksoftware.de>
*
* Published under license:
* Creative Commons Attribution-NonCommercial-ShareAlike 4.0 International 
* https://creativecommons.org/licenses/by-nc-sa/4.0/
*
*/                

// Include the library
use <mod/block.scad>;


// base
lego_brick([0,0,0]   ,[3,4,3],[true,false,"classic"]);
lego_brick([0,0,3]   ,[2,4,3],[true,false,"none"]);
lego_brick([4,0,3]  ,[2,2,3],[true,true,"none"]);
lego_brick([4,2,3]  ,[2,2,3],[false,true,"none"]);
lego_brick([-1,-2,3] ,[1,8,3],[true,false,"classic"]);
difference(){
    lego_brick([4,0,0]  ,[2,4,3],[true,true,"classic"]);
    translate([40,24,0])cylinder(7.2, d=8, $fn=50);
}


module lego_brick(position, shape_size, params) {
    translate([((shape_size[0]/2)+position[0])*8,((shape_size[1]/2)+position[1])*8,position[2]*3.2])brick(shape_size,params);
}

module brick(shape_size,params) {
    
    // Brick size in X-direction specified as multiple of an 1x1 brick.
    brickSizeX = shape_size[0]; // [1:32]  
    // Brick size in Y-direction specified as multiple of an 1x1 brick.
    brickSizeY = shape_size[1]; // [1:32]  
    // Height of brick specified as number of layers. Each layer has the height of one plate.
    baseLayers = shape_size[2]; // [1:24]

    /* [Appearance] */

    // Type of cut-out on the underside.
    baseCutoutType = params[2]; // [none, classic]
    // Whether to draw knobs.
    knobs = params[0];
    // Whether knobs should be centered.
    knobCentered = false;
    // Type of the knobs
    knobType = "classic"; // [classic, technic]

    // Whether to draw pillars.
    pillars = true;

    // Whether brick should have Technic holes along X-axis.
    holesX = params[3];
    // Whether brick should have Technic holes along Y-axis.
    holesY = false;
    // Whether brick should have Technic holes along Z-axis.
    holesZ = params[1];

    // Whether brick should have a pit
    pit = false;
    // Whether knobs should be drawn inside pit
    pitKnobs = false;
    // Pit wall thickness as multiple of one brick side length
    pitWallThickness = 0.333;

    // Slanting size on X0 side specified as multiple of an 1x1 brick.
    slantingX0 = 0;
    // Slanting size on X1 side specified as multiple of an 1x1 brick.
    slantingX1 = 0;
    // Slanting size on Y0 side specified as multiple of an 1x1 brick.
    slantingY0 = 0;
    // Slanting size on Y1 side specified as multiple of an 1x1 brick.
    slantingY1 = 0;

    /* [Quality] */

    // Quality of the preview in relation to the final rendering.
    previewQuality = 0.5; // [0.1:0.1:1]
    // Number of drawn fragments for roundings in the final rendering.
    roundingResolution = 64; // [16:8:128]

    /* [Calibration] */

    // Adjustment of the height (mm)
    baseHeightAdjustment = 0.0;
    // Adjustment of each side (mm)
    baseSideAdjustment = -0.0;
    // Diameter of the knobs (mm)
    knobSize = 5.1;
    // Thickness of the walls (mm)
    wallThickness = 1.5;
    // Diameter of the Z-Tubes (mm)
    tubeZSize = 6.3;

    // Generate the block
    block(
        grid = [brickSizeX, brickSizeY],
        baseLayers = baseLayers,
        baseCutoutType = baseCutoutType,
        
        knobs = knobs,
        knobCentered = knobCentered,
        knobType = knobType,
        
        pillars = pillars,
        
        holesX = holesX,
        holesY = holesY,
        holesZ = holesZ,
        
        pit = pit,
        pitKnobs = pitKnobs,
        pitWallThickness = pitWallThickness,
        
        slanting = ((slantingX0 != 0) || (slantingX1 != 0) || (slantingY0 != 0) || (slantingY1 != 0)) ? [slantingX0, slantingX1, slantingY0, slantingY1] : false, 

        previewQuality = previewQuality,
        baseRoundingResolution = roundingResolution,
        holeRoundingResolution = roundingResolution,
        knobRoundingResolution = roundingResolution,
        pillarRoundingResolution = roundingResolution,

        baseHeightAdjustment = baseHeightAdjustment,
        baseSideAdjustment = baseSideAdjustment,
        knobSize = knobSize,
        wallThickness = wallThickness,
        tubeZSize = tubeZSize
    );
}

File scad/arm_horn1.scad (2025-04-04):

/*      
        Even More Customizable Straight LEGO Technic Beam
        Based on Customizable Straight LEGO Technic Beam
         and Parametric LEGO Technic Beam by "projunk" and "stevemedwin"
        
        www.thingiverse.com/thing:203935
        
        Also uploaded to Prusaprinters.org at https://www.prusaprinters.org/prints/33038-even-more-customizable-straight-beam-for-legotm-te
        
        Modified by Sam Kass
        November 2015
*/

// user parameters

// Hole sequence. o for round hole, + for plus-shaped hole, capital O for sideways hole, capital P for sideways plus, and x for blank spot. eg. "+ooo+", "oOo", "oxPxo", etc.
//holes = ""; // 5 holes with plusses at end

// If true, piece will be half-height
//half_height="false"; // [true, false]
difference() {
    union(){
        rotate([0,0,90])translate([3.7,-34.5,0])drawBeam("xxx",false,1);
        rotate([0,0,0])translate([-2,4.2,0])drawBeam("xxxxx",false,1);
        rotate([0,0,0])translate([0,0,0])drawBeam("xxxxxxoxxo",false,2);
        rotate([0,0,0])translate([32,0,-5])drawBeam("xxxxxo",false,1);
    }
    #translate([-2,8,-1])cylinder(d=5, h=17, $fn=100);
    #translate([-2,8,7.8])cylinder(d=8.5, h=8, $fn=100);
}

/* [Hidden] */

$fn=50*1.0;


Pitch = 8*1.0;
Radius1 = 5.0/2;
Radius2 = 6.1/2;
//Height = half_height=="true"?4.0:7.8*1.0;
Depth = 0.85*1.0;
Width = 7.3*1.0; 
Plus_Width = 2.0*1.0;

Overhang = 0.05*1.0;

module body(holes,Height)
{
    translate([0, Width/2, 0]) 
    hull() {
        cylinder(r=Width/2, h=Height);
        
        translate([(len(holes)-1)*Pitch, 0, 0]) 
            cylinder(r=Width/2, h=Height);
    }
}

module hole(Height)
{
    union()
	{
        //core
        cylinder(r=Radius1,h=Height);
        
        //top countersink
        translate([0,0,Height-Depth+Overhang]) 
            cylinder(r=Radius2,h=Depth);
        
        //bottom countersink
        translate([0,0,-Overhang/2]) 
            cylinder(r=Radius2,h=Depth);
        
        translate([0,0,Depth-Overhang])
            cylinder(h=(Radius2 - Radius1), r1=Radius2, r2=Radius1);
    }
}

module plus(Height) {

    union() {
        translate([-Plus_Width/2, -Radius1, -Overhang]) 
            cube([Plus_Width, Radius1*2, Height+Overhang*2]);
        translate([-Radius1, -Plus_Width/2, -Overhang]) 
            cube([Radius1*2, Plus_Width, Height+Overhang*2]);
    }
}

module drawBeam(holes,half_height,height)
{
    Height = height * (half_height==true?4.0:7.8*1.0);
    difference()
    {
        body(holes,Height);
       
        for (i = [1:len(holes)])
        {
            if (holes[i-1] == "+")
                translate([(i-1)*Pitch, Width/2, 0])
                    plus(Height);
            else if (holes[i-1] == "o")
                translate([(i-1)*Pitch, Width/2, 0])
                    hole(Height);
            else if (holes[i-1] == "O")
                rotate([90,0,0])
                translate([(i-1)*Pitch, Width/2,-Pitch+Depth/2])
                    hole(Height);
            else if (holes[i-1] == "P")
                rotate([90,0,0])
                translate([(i-1)*Pitch, Width/2,-Pitch+Depth/2])
                    plus(Height);
            else if (holes[i-1] == "x") {}
            else
                translate([(i-1)*Pitch, Width/2, 0])
                    hole(Height);
        }
    }
}

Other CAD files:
scad/arm_horn_bridge1.scad
scad/arm_support1.scad
scad/box.scad
scad/channel.scad
scad/mod/base.scad
scad/mod/block.scad
scad/mod/connectors.scad
scad/mod/duo.scad
scad/mod/pcb.scad
scad/mod/plug.scad
scad/mod/shapes.scad
scad/mod/socket.scad
scad/mod/svg3d.scad
scad/mod/text3d.scad
scad/servo_horn1.scad
scad/servo_mount1.scad
scad/servo_support1.scad

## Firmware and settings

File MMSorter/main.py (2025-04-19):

#!/usr/bin/env pybricks-micropython
from ev3_manager import EV3Manager
from pybricks.tools import wait

# Initialize color sorter
color_sorter = EV3Manager()

def perform_sort_action(color):
    """Perform the sort action based on the detected color."""
    action = color_sorter.config['sort_action'][color]
    servo_num = action['servo']
    # Beep with the color-specific frequency
    color_sorter.beep(frequency=action['beep'], duration=100)
    color_sorter.reset()
    # Open the servo to let the object pass to the designated bin
    print("Opening servo [{}] for color [{}]".format(servo_num, color))
    color_sorter.servo_set(servo_num, action['open'])
    print("Waiting [{}]".format(action['wait_ms']))
    wait(action['wait_ms'])
    color_sorter.beep(frequency=300, duration=100)
    # Close the servo after sorting
    print("Closing servo [{}] for color [{}]".format(servo_num, color))
    color_sorter.servo_set(servo_num, action['close'])

def main():
    if color_sorter.keep_running: # check if initialization was ok
        print("Ready...")
        color_sorter.wait_for_start()
        color_sorter.beep()
        color_sorter.reset()
        color_sorter.motor_belt_run()
        print("Press touch sensor to finish...")
        while color_sorter.keep_running:
            detected_color = color_sorter.color_sensor_read()
            if detected_color is not None:
                print("Recognised color [{}] ".format(detected_color))
                perform_sort_action(detected_color)
            wait(10) # to lower CPU load

        # Stop the belt and reset servos at the end
        color_sorter.turn_off()
        print("...End")

if __name__ == '__main__':
    main()

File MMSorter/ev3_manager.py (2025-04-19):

from pybricks.hubs import EV3Brick
from pybricks.ev3devices import TouchSensor, ColorSensor, Motor
from pybricks.iodevices import I2CDevice
from pybricks.parameters import Port, Direction, Color
from pybricks.tools import wait
from pybricks.media.ev3dev import SoundFile, ImageFile
import time

class EV3Manager:
    VOLTAGE_REGISTER = 0x41
    config = {
        'color_sensor': {
            'buffer_size': 8,            # Number of measurements for color
            'belt_threshold': 15,         # Maximum allowed non-valid readings before giving up
            'stability_threshold': 0.7,   # Fraction of identical readings required for stability
            'sample_interval_ms': 20,     # Interval between color measurements in ms
            'valid_colors': {
                Color.RED,
                Color.GREEN,
                Color.BLUE,
                Color.YELLOW,
                Color.BROWN,
                Color.WHITE
            }
        },
        'servo': {
            1: {
                'nxt_register': 0x42,
                'reset_position': 1500,
                'calibration': 20
            },
            2: {
                'nxt_register': 0x44,
                'reset_position': 1500,
                'calibration': 20
            },
            3: {
                'nxt_register': 0x46,
                'reset_position': 1500,
                'calibration': -15
            }
        },
        'sort_action': {
            Color.BLUE: {
                'servo': 1,
                'open': 2000,
                'close': 1500,
                'beep': 600,
                'wait_ms': 2500
            },
            Color.YELLOW: {
                'servo': 1,
                'open': 1000,
                'close': 1500,
                'beep': 800,
                'wait_ms': 2500
            },
            Color.GREEN: {
                'servo': 2,
                'open': 2000,
                'close': 1500,
                'beep': 700,
                'wait_ms': 3000
            },
            Color.WHITE: {
                'servo': 2,
                'open': 1000,
                'close': 1500,
                'beep': 900,
                'wait_ms': 3000
            },
            Color.RED: {
                'servo': 3,
                'open': 2000,
                'close': 1500,
                'beep': 500,
                'wait_ms': 4200
            },
            Color.BROWN: {
                'servo': 3,
                'open': 1000,
                'close': 1500,
                'beep': 1000,
                'wait_ms': 4200
            }
        }
    }

    def __init__(self):
        self.keep_running = True
        try:
            self.ev3 = EV3Brick()
            self.touch = TouchSensor(Port.S4)
            self.color = ColorSensor(Port.S2)
            self.motor_belt = Motor(Port.A, Direction.COUNTERCLOCKWISE)
            self.nxtservo = I2CDevice(Port.S3, 0x58) # I2C device on Port S3 with NXTServo's address
        except Exception as e:
            self.handle_error("Master Initialization error", e)
            self.keep_running = False

    def handle_error(self, msg, error):
        print("[ERROR] {}: {}".format(msg, error))
        self.beep(frequency=200, duration=500)
        # self.keep_running = False

    def beep(self, frequency=3000, duration=200):
        try:
            self.ev3.speaker.beep(frequency=frequency, duration=duration)
        except Exception as e:
            self.handle_error("Beep error", e)

    def read_voltage(self):
        """Read and return the voltage from the nxtservo."""
        return self.nxtservo.read(self.VOLTAGE_REGISTER)

    def wait_for_start(self):
        print("Waiting for touch sensor to start...")
        while not self.touch_check(0):
            wait(10)
        self.beep(frequency=3000, duration=100)
        self.running = True

    def touch_check(self, where = -1):
        try:
            if self.touch.pressed():
                print("Pressed [{}]".format(where))
                return True
            return False
        except Exception as e:
            self.handle_error("Touch sensor error [{}] {}".format(where), e)
            return False

    def touch_check_exit(self, where = -1):
        if self.touch_check(where):
            print("Touch sensor pressed to stop.")
            self.keep_running = False

    def motor_belt_run(self, speed=150):
        try:
            print("Starting belt motor...")
            self.motor_belt.run(speed)
        except Exception as e:
            self.handle_error("Belt Motor run error", e)

    def motor_belt_stop(self):
        try:
            print("Stopping belt motor...")
            self.motor_belt.stop()
        except Exception as e:
            self.handle_error("Belt Motor stop error", e)

    def color_calculate_most_common(self, buffer):
        """Return the most frequently detected color and its count."""
        freq = {}
        for color in buffer:
            if color is not None:
                freq[color] = freq.get(color, 0) + 1
        if not freq:
            return None, 0
        common_color, count = max(freq.items(), key=lambda item: item[1])
        return common_color, count

    def color_get(self):
        try:
            return self.color.color()
        except Exception as e:
            self.handle_error("Color sensor error", e)
            return None

    def color_sensor_read(self):
        """
        Sample the color sensor until a stable reading is obtained or the belt is undetected.
        Returns a color or None if a stable color is not detected.
        """
        color_buffer = []
        belt_detected = 0
        while (
            self.keep_running
            and len(color_buffer) < self.config['color_sensor']['buffer_size']
            ):
            current_color = self.color_get()
            if current_color in self.config['color_sensor']['valid_colors']:
                color_buffer.append(current_color)
                belt_detected = 0  # reset if a valid color is read
            else:
                belt_detected += 1
            wait(self.config['color_sensor']['sample_interval_ms'])
            self.touch_check_exit(1)

        if len(color_buffer) >= self.config['color_sensor']['buffer_size']:
            common_color, count = self.color_calculate_most_common(color_buffer)
            if count / len(color_buffer) < self.config['color_sensor']['stability_threshold']:
                return None
            return common_color
        return None
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

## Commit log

2025-04-02 initial files updates arm holder
    [Battery_Dummy_Cut_Negativ.stl, Battery_Dummy_Cut_Positiv.stl, arm_holder.scad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]
2025-04-03 stl and scad updates
    [arm_holder.scad, arm_holder1.scad, arm_horn1.scad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]
2025-04-04 stl updates
    [arm_holder1.scad, arm_horn1.scad, arm_horn1.stl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]
2025-04-06 update calibration
2025-04-08 add new scads
    [channel.scad]
